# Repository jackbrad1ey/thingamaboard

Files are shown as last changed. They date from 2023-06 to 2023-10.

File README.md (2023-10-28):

# Thingamaboard

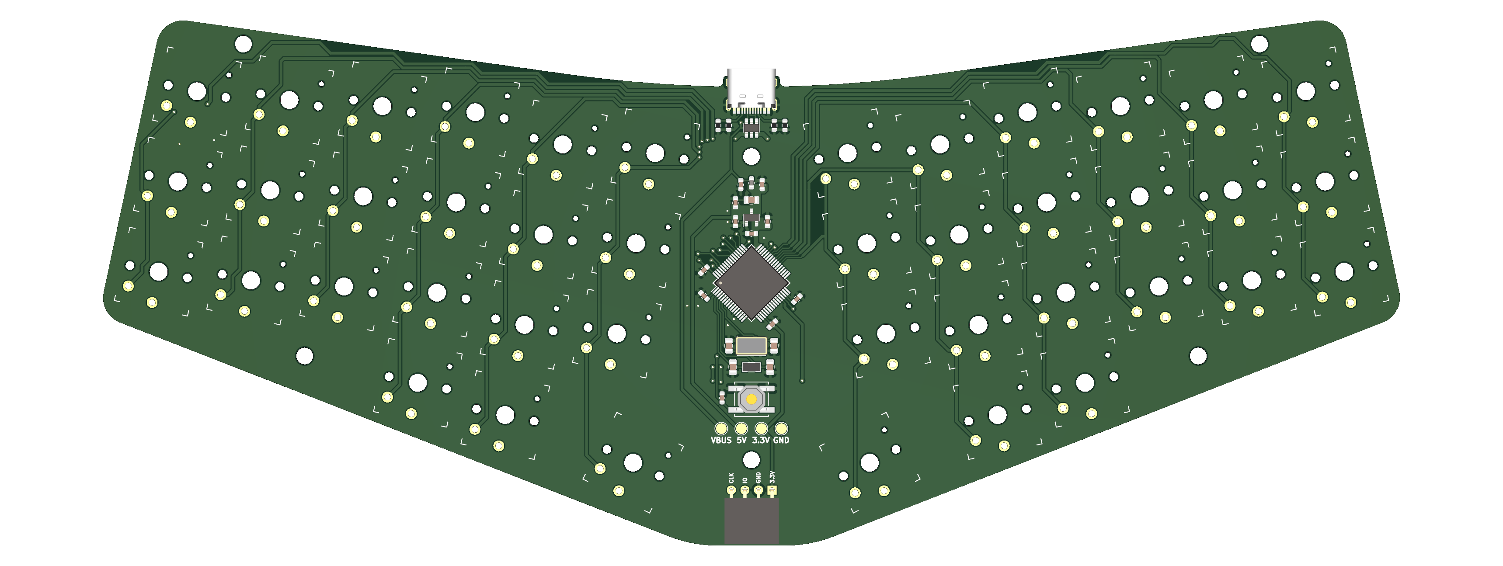
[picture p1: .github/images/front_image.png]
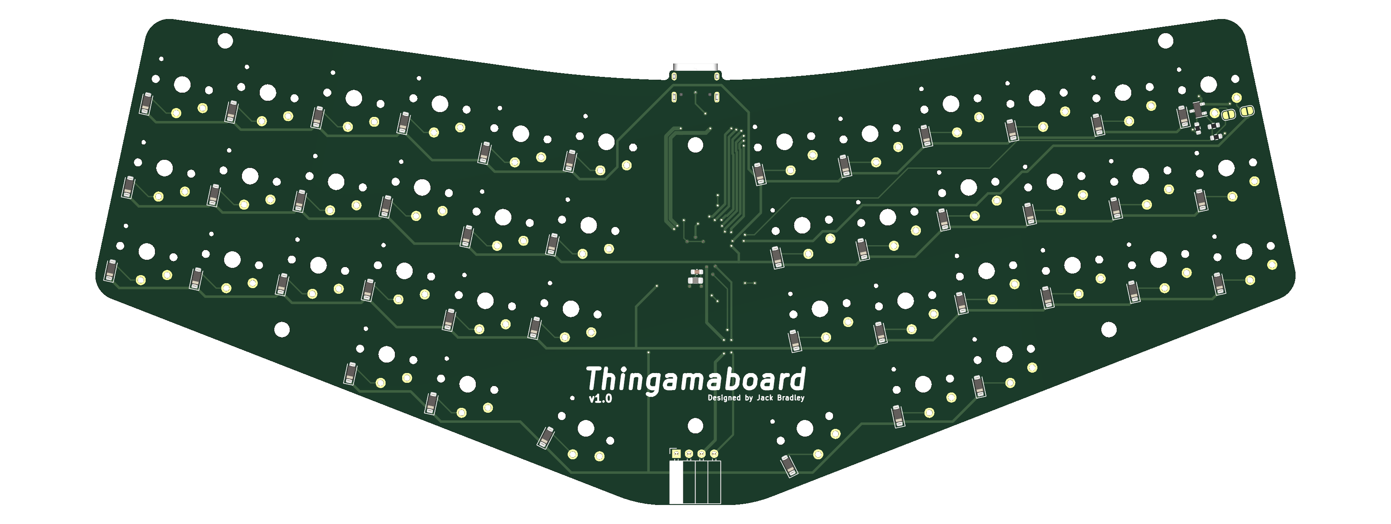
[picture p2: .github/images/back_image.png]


A custom keyboard designed and manufactured for myself. Programmed using STM32CubeIDE and Jetbrains Fleet, designed using [Ergogen](https://github.com/ergogen/ergogen), AutoCAD and Solidworks. This board was developed with portability and ergonomics in mind. It adopts a columnar, alice-like layout with three-key thumb clusters, allowing for ergonomic typing in a relatively small and portable form factor.

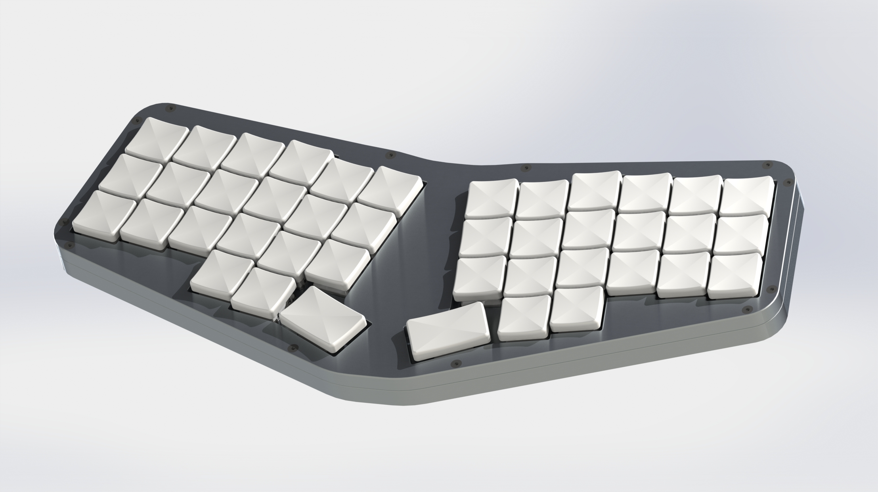
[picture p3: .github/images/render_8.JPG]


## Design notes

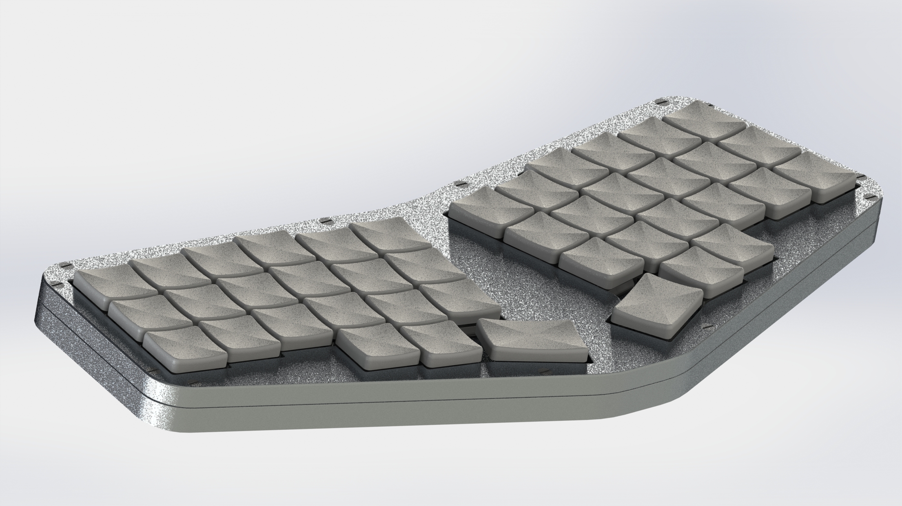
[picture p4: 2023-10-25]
.github/images/render_2.JPG

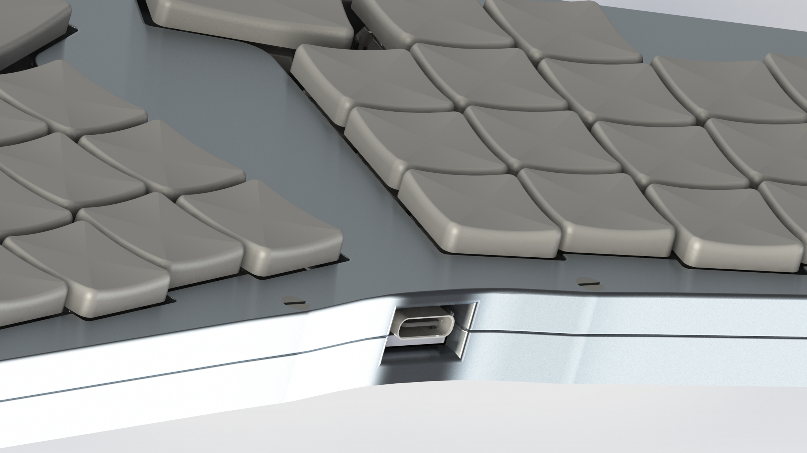
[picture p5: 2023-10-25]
.github/images/render_4.JPG

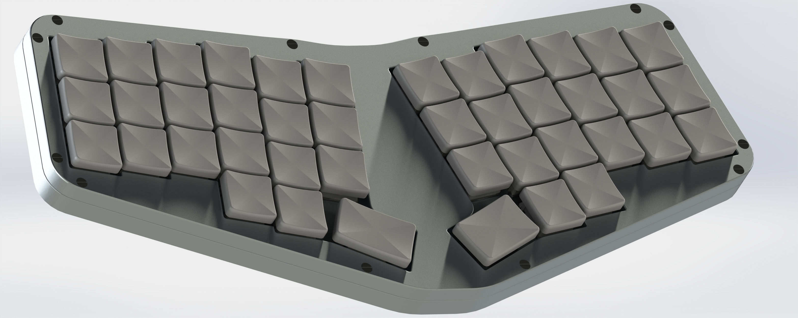
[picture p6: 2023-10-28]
.github/images/render_7.JPG

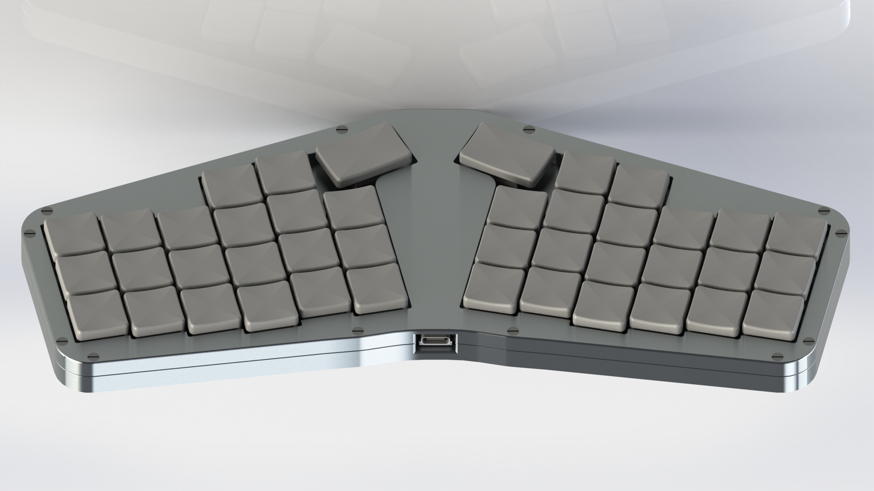
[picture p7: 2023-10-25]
.github/images/render_6.JPG

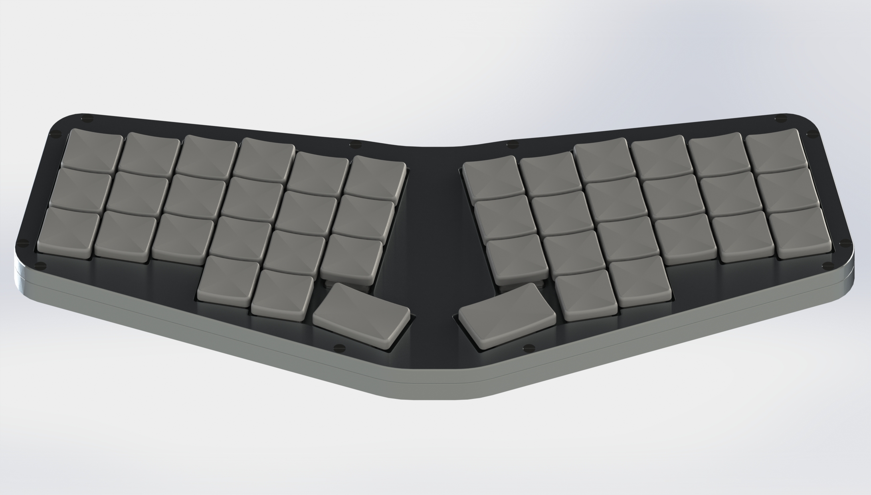
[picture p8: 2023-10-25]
.github/images/render_5.JPG

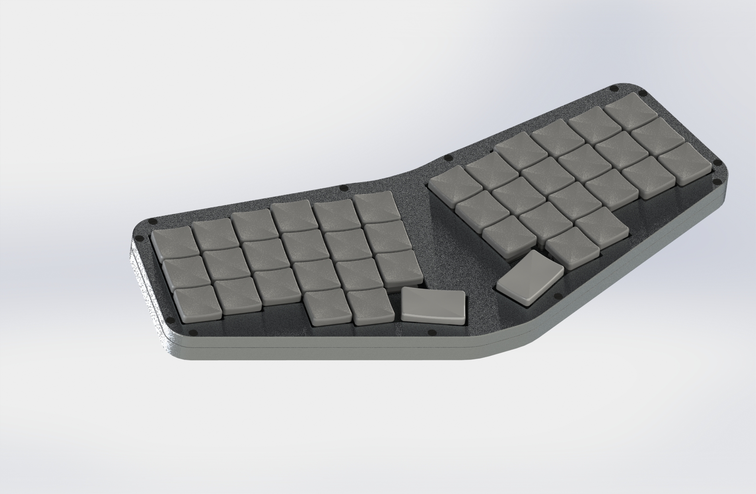
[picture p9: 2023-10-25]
.github/images/render_1.JPG

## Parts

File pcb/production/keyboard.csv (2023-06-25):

Comment | Designator | Footprint | LCSC
10n | C1,C10 | Capacitor_SMD:C_0603_1608Metric
4.7u | C14 | Capacitor_SMD:C_0603_1608Metric
0.1u | C17 | Capacitor_SMD:C_0603_1608Metric
100n | C2 | Capacitor_SMD:C_0603_1608Metric
10u | C3 | Capacitor_SMD:C_0805_2012Metric | C396720
1u | C4,C13,C16 | Capacitor_SMD:C_0603_1608Metric
100nF | C5,C11,C12,C15 | Capacitor_SMD:C_0603_1608Metric
33p | C6,C8 | Capacitor_SMD:C_0805_2012Metric | C157687
15p | C7,C9 | Capacitor_SMD:C_0805_2012Metric | C1562
D_Small | D1,D2,D3,D4,D5,D6,D7,D8,D9,D10,D11,D12,D13,D14,D15,D16,D17,D18,D19,D20,D21,D22,D23,D24,D25,D26,D27,D28,D29,D30,D31,D32,D33,D34,D35,D36,D37,D38,D39,D40,D41,D42 | Diode_SMD:D_SOD-123 | C2099
FerriteBead_Small | FB1 | Inductor_SMD:L_0603_1608Metric | C80165
MountingHole | H1,H2,H3,H4,H5,H6 | MountingHole:MountingHole_3.2mm_M3
USB_C_Receptacle_USB2.0 | J1 | local-library:TYPE-C-31-M-12 | C165948
Conn_01x04 | J2 | Connector_PinSocket_2.54mm:PinSocket_1x04_P2.54mm_Horizontal | C2897386
bridge | JP1,JP2 | Jumper:SolderJumper-2_P1.3mm_Open_RoundedPad1.0x1.5mm
10u | L1 | Inductor_SMD:L_0805_2012Metric
BC858 | Q2 | Package_TO_SOT_SMD:SOT-23 | C81569
10.2k | R1,R2,R3,R4,R5,R8 | Resistor_SMD:R_0603_1608Metric
1.91k | R7 | Resistor_SMD:R_0603_1608Metric
SW_Push | SW1,SW2,SW3,SW4,SW5,SW6,SW7,SW8,SW9,SW10,SW11,SW12,SW13,SW14,SW15,SW16,SW17,SW18,SW19,SW20,SW21,SW22,SW23,SW24,SW25,SW26,SW27,SW28,SW29,SW30,SW31,SW32,SW33,SW34,SW35,SW36,SW37,SW38,SW39,SW40,SW41,SW42 | local-library:SW_PG1350
TS-1187A-B-A-B | SW43 | Button_Switch_SMD:SW_Push_1P1T_NO_CK_KSC6xxJ | C318884
~ | TP1,TP2,TP3,TP4 | TestPoint:TestPoint_Pad_D2.0mm
LP3993-33B3F | U1 | Package_TO_SOT_SMD:SOT-23 | C387705
USBLC6-2SC6 | U2 | Package_TO_SOT_SMD:SOT-23-6 | C2827654
STM32F411RETx | U3 | Package_QFP:LQFP-64_10x10mm_P0.5mm
12MHz | Y1 | Crystal:Crystal_SMD_5032-4Pin_5.0x3.2mm
32.768k | Y2 | Crystal:Crystal_SMD_3215-2Pin_3.2x1.5mm | C620155

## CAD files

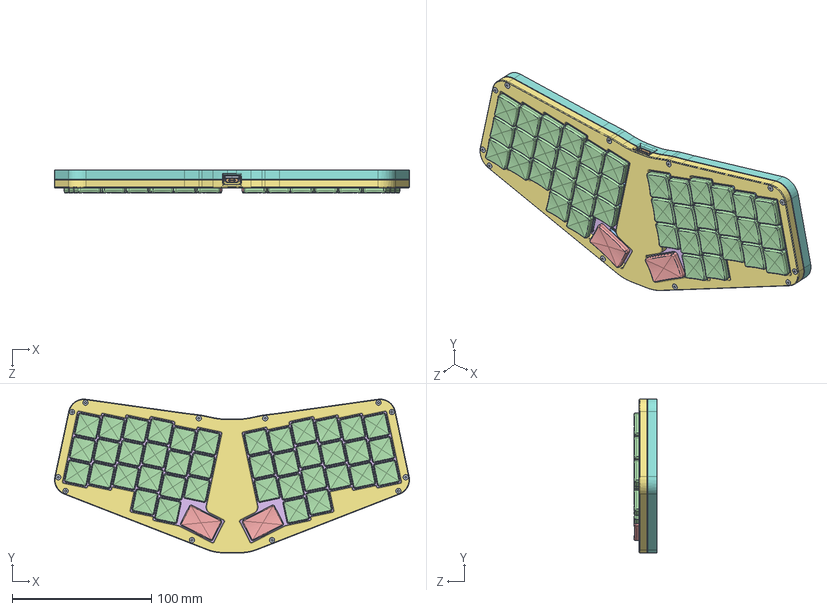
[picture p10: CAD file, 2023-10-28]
cad/thingamaboard.SLDASM
254.7 x 110.4 x 16.6 mm
pcb_base
usb_c_connector
kailh_choc_switch x 42
1U-keycap x 40
1.5U-keycap x 2
plate
new_top_piece
bottom_piece
M2_screws x 12

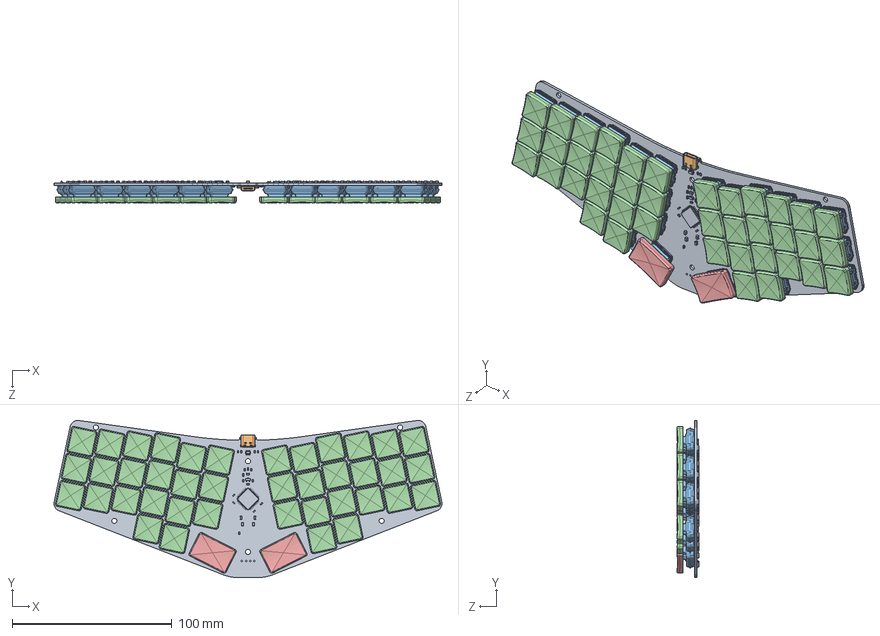
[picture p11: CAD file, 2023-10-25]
cad/pcb/pcb.SLDASM
242.5 x 98.2 x 13.8 mm
pcb_base
usb_c_connector
kailh_choc_switch x 42
1U-keycap x 40
1.5U-keycap x 2

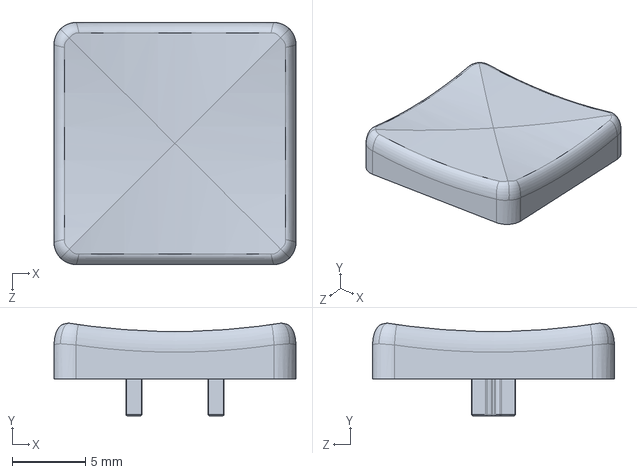
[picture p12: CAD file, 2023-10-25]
cad/pcb/1U-keycap.SLDPRT
16.5 x 6.32 x 16.5 mm

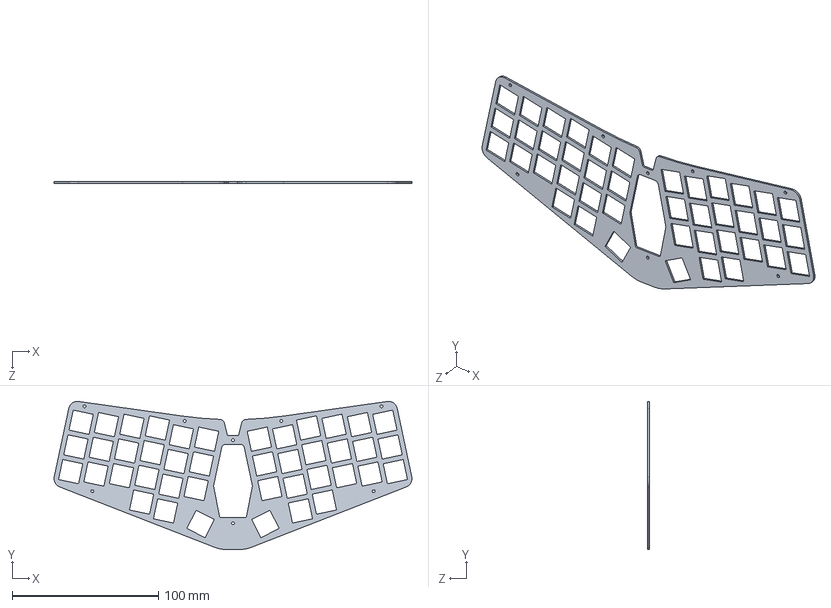
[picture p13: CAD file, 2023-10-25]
cad/plate/plate.SLDPRT
244.5 x 101.2 x 1.20 mm

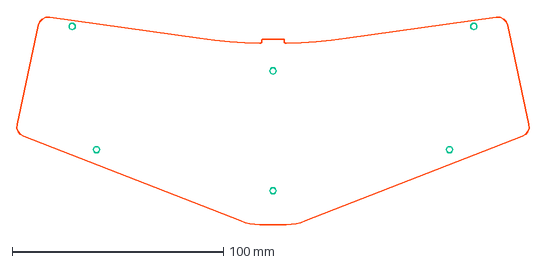
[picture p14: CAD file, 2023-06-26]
layout/pcb_shape.dxf
243.3 x 98.5 mm

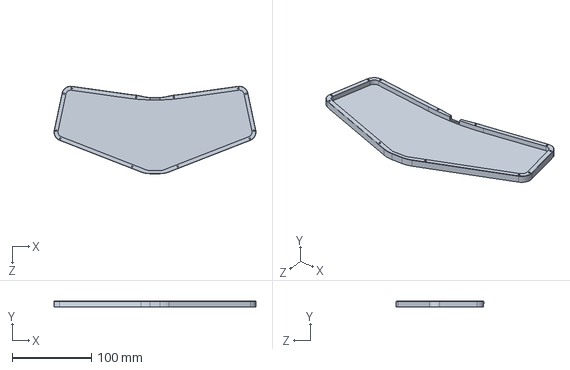
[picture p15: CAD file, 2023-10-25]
cad/case/bottom_piece.SLDPRT
254.7 x 7.00 x 110.4 mm

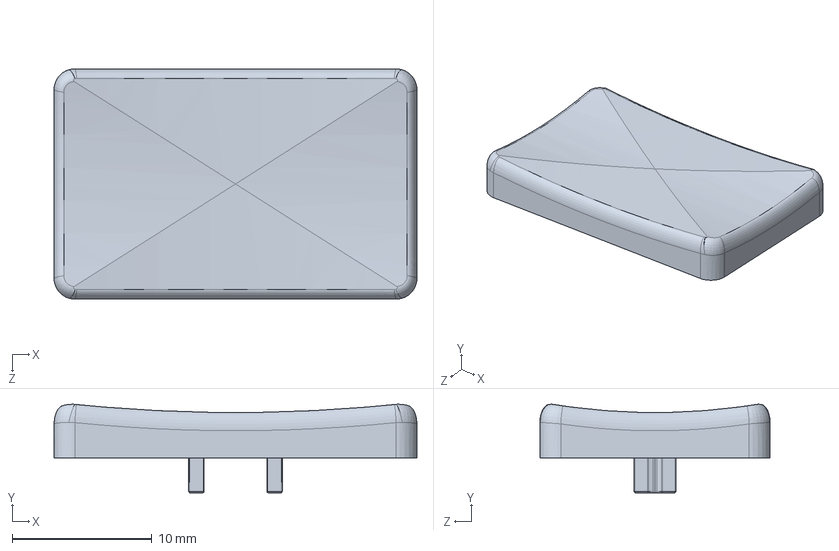
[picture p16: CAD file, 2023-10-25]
cad/pcb/1.5U-keycap.SLDPRT
26.0 x 6.35 x 16.5 mm

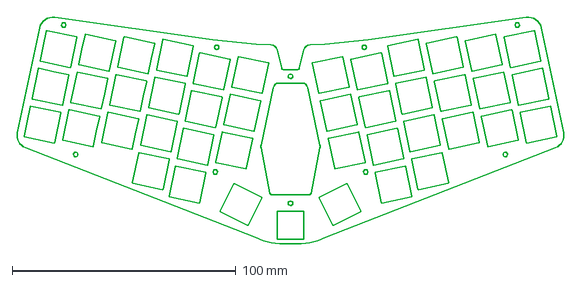
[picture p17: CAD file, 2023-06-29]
cad/plate/plate_outline.dxf
245.5 x 101.6 mm

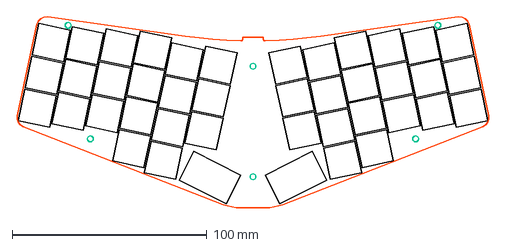
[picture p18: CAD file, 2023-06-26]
layout/pcb_layout.dxf
243.3 x 98.5 mm

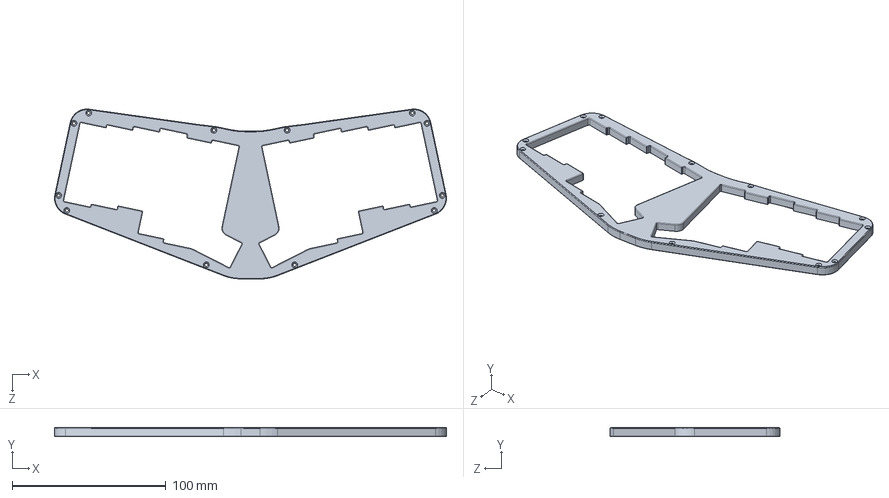
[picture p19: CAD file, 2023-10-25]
cad/case/new_top_piece.SLDPRT
254.7 x 6.00 x 110.4 mm

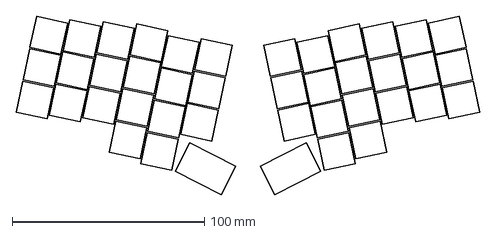
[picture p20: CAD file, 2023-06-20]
layout/key_layout.dxf
241.3 x 92.7 mm

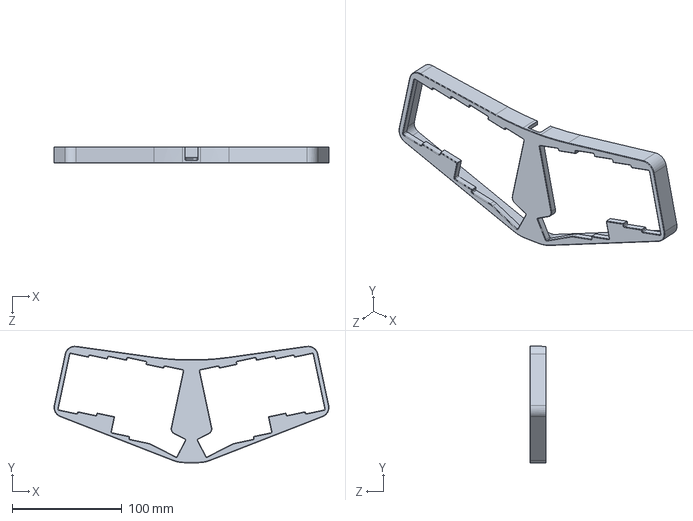
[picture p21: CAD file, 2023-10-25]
cad/case/top_piece.SLDPRT
250.5 x 106.2 x 15.0 mm

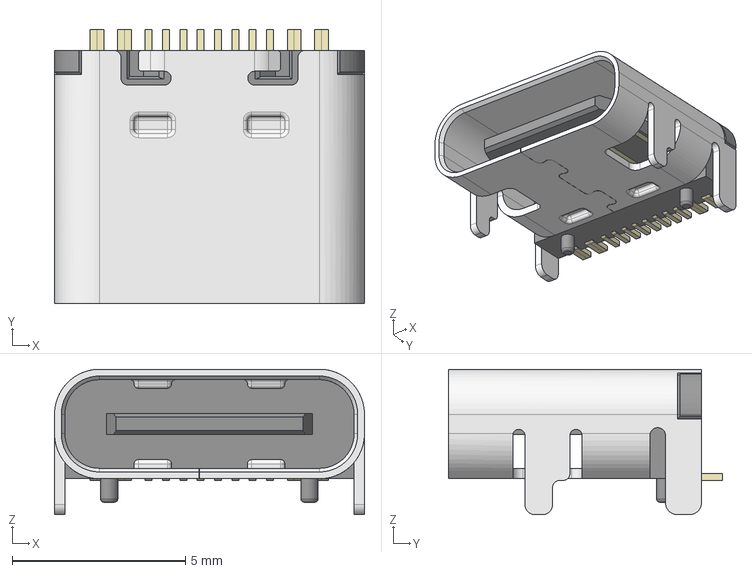
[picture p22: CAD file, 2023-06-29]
cad/pcb/usb_c_connector.step
8.95 x 7.90 x 4.20 mm

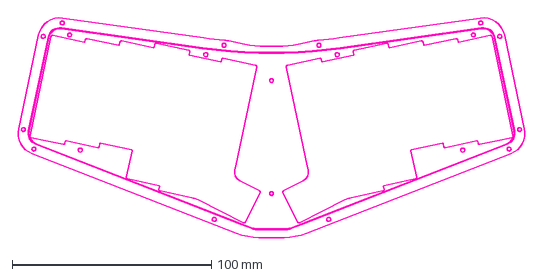
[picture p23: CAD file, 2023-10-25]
cad/case/case_mount_outline.dxf
256.5 x 111.1 mm

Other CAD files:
cad/outlines.dwg
cad/pcb/kailh_choc_switch.SLDPRT
cad/pcb/female_1x4_2.54mm_header.SLDPRT
cad/case/M2_screws.SLDPRT
cad/case/case_mount_outline.dwg
cad/pcb/usb_c_connector.SLDPRT
layout/pcb_layout.dwg

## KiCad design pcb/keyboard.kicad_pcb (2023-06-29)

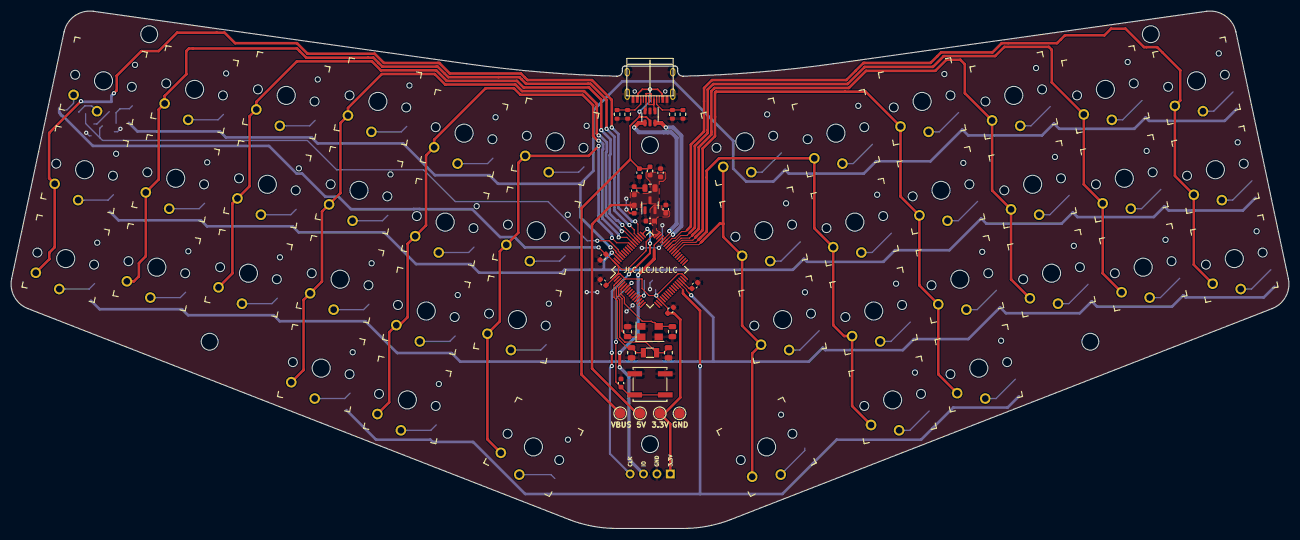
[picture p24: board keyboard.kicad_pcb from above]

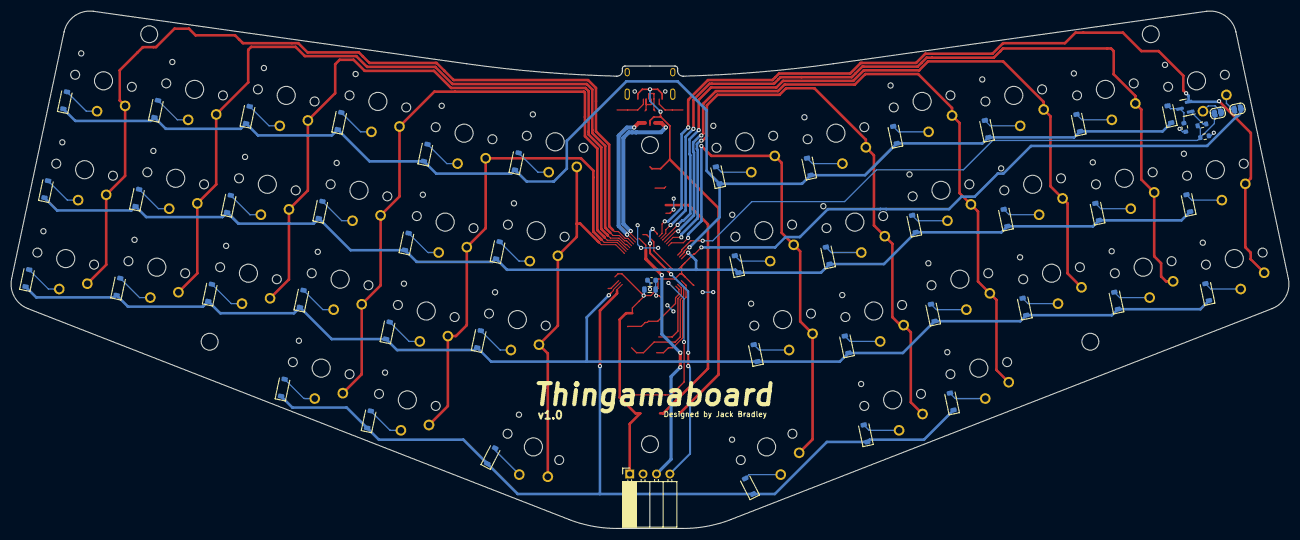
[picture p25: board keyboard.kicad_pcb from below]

Board: 2 copper layers, 242.5 x 98.2 mm, 131 parts (51 on the bottom side), 81 nets.

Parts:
C1, C10: 10n; C_0603_1608Metric
C2: 100n; C_0603_1608Metric
C3: 10u; C_0805_2012Metric
C4, C13, C16: 1u; C_0603_1608Metric
C5, C11, C12, C15: 100nF; C_0603_1608Metric
C6, C8: 33p; C_0805_2012Metric
C7, C9: 15p; C_0805_2012Metric
C14: 4.7u; C_0603_1608Metric
C17: 0.1u; C_0603_1608Metric
D1, D2, D3, D4, D5, D6, D7, D8, D9, D10, D11, D12, D13, D14, D15, D16, D17, D18, D19, D20, D21, D22, D23, D24, D25, D26, D27, D28, D29, D30, D31, D32, D33, D34, D35, D36, D37, D38, D39, D40, D41, D42: D_Small; D_SOD-123
FB1: FerriteBead_Small; L_0603_1608Metric
H1, H2, H3, H4, H5, H6: MountingHole; MountingHole_3.2mm_M3
J1: USB_C_Receptacle_USB2.0; TYPE-C-31-M-12
J2: Conn_01x04; PinSocket_1x04_P2.54mm_Horizontal
JP1, JP2: bridge; SolderJumper-2_P1.3mm_Open_RoundedPad1.0x1.5mm
L1: 10u; L_0805_2012Metric
Q2: BC858; SOT-23
R1, R2, R3, R4, R5, R8: 10.2k; R_0603_1608Metric
R7: 1.91k; R_0603_1608Metric
SW1, SW2, SW3, SW4, SW5, SW6, SW7, SW8, SW9, SW10, SW11, SW12, SW13, SW14, SW15, SW16, SW17, SW18, SW19, SW20, SW21, SW22, SW23, SW24, SW25, SW26, SW27, SW28, SW29, SW30, SW31, SW32, SW33, SW34, SW35, SW36, SW37, SW38, SW39, SW40, SW41, SW42: SW_Push; SW_PG1350
SW43: TS-1187A-B-A-B; SW_Push_1P1T_NO_CK_KSC6xxJ
TP1, TP2, TP3, TP4: TestPoint_Pad_D2.0mm
U1: LP3993-33B3F; SOT-23
U2: USBLC6-2SC6; SOT-23-6
U3: STM32F411RETx; LQFP-64_10x10mm_P0.5mm
Y1: 12MHz; Crystal_SMD_5032-4Pin_5.0x3.2mm
Y2: 32.768k; Crystal_SMD_3215-2Pin_3.2x1.5mm

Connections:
+3V3: C10.1, C11.1, C12.1, C13.1, C16.1, J2.1, JP1.2 (B), L1.1, TP4.1, U1.2 (VOUT), U3.1 (VBAT), U3.19 (VDD), U3.32 (VDD), U3.48 (VDD), U3.64 (VDD)
+5V: C2.1, C3.1, C4.1, C5.1, FB1.2, TP2.1, U1.3 (VIN)
/connectors/CC1: J1.A5 (CC1), R1.1, R2.1
/connectors/CC2: J1.B5 (CC2), R3.1, R4.1
/connectors/SWCLK: J2.4, U3.49 (PA14)
/connectors/SWDIO: J2.3, U3.46 (PA13)
/connectors/USB_D+: U2.4 (I/O2), U3.45 (PA12)
/connectors/USB_D-: U2.6 (I/O1), U3.44 (PA11)
/inputs/BOOT0: JP2.1 (A), R5.1, R7.1, U3.60 (BOOT0)
/inputs/NRST: C17.1, SW43.2, U3.7 (NRST)
/inputs/S1_OUT: D1.2 (A), Q2.3 (C), R8.1
/inputs/col0: Q2.2 (E), SW2.2, SW3.2, U3.50 (PA15)
/inputs/col1: SW4.2, SW5.2, SW6.2, U3.51 (PC10)
/inputs/col2: SW7.2, SW8.2, SW9.2, U3.52 (PC11)
/inputs/col3: SW10.2, SW11.2, SW12.2, SW13.2, U3.53 (PC12)
/inputs/col4: SW14.2, SW15.2, SW16.2, SW17.2, U3.54 (PD2)
/inputs/col5: SW18.2, SW19.2, SW20.2, SW21.2, U3.55 (PB3)
/inputs/col6: SW22.2, SW23.2, SW24.2, SW25.2, U3.38 (PC7)
/inputs/col7: SW26.2, SW27.2, SW28.2, SW29.2, U3.39 (PC8)
/inputs/col8: SW30.2, SW31.2, SW32.2, SW33.2, U3.40 (PC9)
/inputs/col9: SW34.2, SW35.2, SW36.2, U3.41 (PA8)
/inputs/col10: SW37.2, SW38.2, SW39.2, U3.42 (PA9)
/inputs/col11: SW40.2, SW41.2, SW42.2, U3.43 (PA10)
/inputs/row0: D1.1 (K), D4.1 (K), D7.1 (K), D10.1 (K), D14.1 (K), D18.1 (K), D22.1 (K), D26.1 (K), D30.1 (K), D34.1 (K), D37.1 (K), D40.1 (K), U3.61 (PB8)
/inputs/row1: D2.1 (K), D5.1 (K), D8.1 (K), D11.1 (K), D15.1 (K), D19.1 (K), D23.1 (K), D27.1 (K), D31.1 (K), D35.1 (K), D38.1 (K), D41.1 (K), U3.62 (PB9)
/inputs/row2: D3.1 (K), D6.1 (K), D9.1 (K), D12.1 (K), D16.1 (K), D20.1 (K), D24.1 (K), D28.1 (K), D32.1 (K), D36.1 (K), D39.1 (K), D42.1 (K), U3.29 (PB10)
/inputs/row3: D13.1 (K), D17.1 (K), D21.1 (K), D25.1 (K), D29.1 (K), D33.1 (K), U3.28 (PB2)
/stm32/HSEO_IN: C6.1, U3.5 (PH0), Y1.1
/stm32/HSEO_OUT: C8.1, U3.6 (PH1), Y1.3
/stm32/LSEO_IN: C7.1, U3.3 (PC14), Y2.1
/stm32/LSEO_OUT: C9.1, U3.4 (PC15), Y2.2
GND: C1.2, C2.2, C3.2, C4.2, C5.2, C6.2, C7.2, C8.2, C9.2, C10.2, C11.2, C12.2, C13.2, C14.2, C15.2, C16.2, C17.2, J1.A1 (GND), J1.A12 (GND), J1.B1 (GND), J1.B12 (GND), J1.S1 (SHIELD), J2.2, R1.2, R2.2, R3.2, R4.2, R5.2, R8.2, SW43.1, TP3.1, U1.1 (GND), U2.2 (GND), U3.12 (VSSA), U3.18 (VSS), U3.31 (VSS), U3.47 (VSS), U3.63 (VSS), Y1.2, Y1.4
unnamed: D2.2 (A), SW2.1
unnamed: D3.2 (A), SW3.1
unnamed: D4.2 (A), SW4.1
unnamed: D5.2 (A), SW5.1
unnamed: D6.2 (A), SW6.1
unnamed: D7.2 (A), SW7.1
unnamed: D8.2 (A), SW8.1
unnamed: D9.2 (A), SW9.1
unnamed: D10.2 (A), SW10.1
unnamed: D11.2 (A), SW11.1
unnamed: D12.2 (A), SW12.1
unnamed: D13.2 (A), SW13.1
unnamed: D14.2 (A), SW14.1
unnamed: D15.2 (A), SW15.1
unnamed: D16.2 (A), SW16.1
unnamed: D17.2 (A), SW17.1
unnamed: D18.2 (A), SW18.1
unnamed: D19.2 (A), SW19.1
unnamed: D20.2 (A), SW20.1
unnamed: D21.2 (A), SW21.1
unnamed: D22.2 (A), SW22.1
unnamed: D23.2 (A), SW23.1
unnamed: D24.2 (A), SW24.1
unnamed: D25.2 (A), SW25.1
unnamed: D26.2 (A), SW26.1
unnamed: D27.2 (A), SW27.1
unnamed: D28.2 (A), SW28.1
unnamed: D29.2 (A), SW29.1
unnamed: D30.2 (A), SW30.1
unnamed: D31.2 (A), SW31.1
unnamed: D32.2 (A), SW32.1
unnamed: D33.2 (A), SW33.1
unnamed: D34.2 (A), SW34.1
unnamed: D35.2 (A), SW35.1
unnamed: D36.2 (A), SW36.1
unnamed: D37.2 (A), SW37.1
unnamed: D38.2 (A), SW38.1
unnamed: D39.2 (A), SW39.1
unnamed: D40.2 (A), SW40.1
unnamed: D41.2 (A), SW41.1
unnamed: D42.2 (A), SW42.1
unnamed: J1.A6 (D+), J1.B6 (D+), U2.3 (I/O2)
unnamed: J1.A7 (D-), J1.B7 (D-), U2.1 (I/O1)
unnamed: JP1.1 (A), SW1.2
unnamed: JP2.2 (B), SW1.1
unnamed: Q2.1 (B), R7.2
unnamed: C14.1, U3.30 (VCAP1)
unnamed: C15.1, L1.2, U3.13 (VDDA)
VBUS: C1.1, FB1.1, J1.A4 (VBUS), J1.A9 (VBUS), J1.B4 (VBUS), J1.B9 (VBUS), TP1.1, U2.5 (VBUS)

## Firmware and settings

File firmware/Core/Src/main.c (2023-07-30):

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
/* Includes ------------------------------------------------------------------*/
#include "main.h"
#include "usb_device.h"

/* USER CODE BEGIN Includes */
#include "key_scan.h"
#include "keycodes.h"
#include "usbd_hid.h"
/* USER CODE END Includes */

TIM_HandleTypeDef htim2;

/* USER CODE BEGIN PV */
extern USBD_HandleTypeDef hUsbDeviceFS;

int keys[KEYS_PER_REPORT] = {KEY_NONE};
int modifier_byte = 0;

void delay_us(uint16_t us) {
	__HAL_TIM_SET_COUNTER(&htim2, 0);  // reset counter back to 0
	while (__HAL_TIM_GET_COUNTER(&htim2) < us);  // wait for the counter to reach desired time
}

uint8_t HID_IsIdle(USBD_HandleTypeDef *pdev) {
	return ((USBD_HID_HandleTypeDef *)pdev->pClassData)->state == HID_IDLE;
}

/* USER CODE END PV */

void SystemClock_Config(void);
static void MX_GPIO_Init(void);
static void MX_TIM2_Init(void);
/**
  * @brief  The application entry point.
  * @retval int
  */
int main(void)
{
  /* MCU Configuration--------------------------------------------------------*/

  /* Reset of all peripherals, Initializes the Flash interface and the Systick. */
  HAL_Init();

  /* Configure the system clock */
  SystemClock_Config();

  /* Initialize all configured peripherals */
  MX_GPIO_Init();
  MX_USB_DEVICE_Init();
  MX_TIM2_Init();
  /* USER CODE BEGIN 2 */
  HAL_TIM_Base_Start(&htim2);
  Keyboard report = (Keyboard) {0, 0, KEY_NONE, KEY_NONE, KEY_NONE, KEY_NONE, KEY_NONE, KEY_NONE};
  /* USER CODE END 2 */

  /* Infinite loop */
  /* USER CODE BEGIN WHILE */
  while (1)
  {
    /* USER CODE END WHILE */

    /* USER CODE BEGIN 3 */
//	HAL_Delay(7);
	// wait until our last report has been read
	if (!HID_IsIdle(&hUsbDeviceFS)) {
		continue;
	}

	scan_keys(keys, &modifier_byte);
	report = (Keyboard) {modifier_byte, 0, keys[0], keys[1], keys[2], keys[3], keys[4], keys[5]};

	USBD_HID_SendReport(&hUsbDeviceFS, &report, sizeof(report));

	for (int i=0; i < KEYS_PER_REPORT; i++) {
		keys[i] = KEY_NONE;
	}
	modifier_byte = 0;

//	report = (Keyboard) {0, 0, KEY_H, KEY_I, 0, 0, 0, 0};
//	USBD_HID_SendReport(&hUsbDeviceFS, &report, sizeof(report));
//	HAL_Delay(50);
//	report = (Keyboard) {0, 0, 0, 0, 0, 0, 0, 0};
//	USBD_HID_SendReport(&hUsbDeviceFS, &report, sizeof(report));
//	HAL_Delay(2000);
  }
  /* USER CODE END 3 */
}

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


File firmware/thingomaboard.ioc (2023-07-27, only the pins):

Mcu.UserName=STM32F411RETx
PA10.Signal=GPIO_Output
PA11.Signal=USB_OTG_FS_DM
PA12.Signal=USB_OTG_FS_DP
PA13.Signal=SYS_JTMS-SWDIO
PA14.Signal=SYS_JTCK-SWCLK
PA15.Signal=GPIO_Output
PA8.Signal=GPIO_Output
PA9.Signal=GPIO_Output
PB10.Signal=GPIO_Input
PB2.Signal=GPIO_Input
PB3.Signal=GPIO_Output
PB8.Signal=GPIO_Input
PB9.Signal=GPIO_Input
PC10.Signal=GPIO_Output
PC11.Signal=GPIO_Output
PC12.Signal=GPIO_Output
PC14-OSC32_IN.Signal=RCC_OSC32_IN
PC15-OSC32_OUT.Signal=RCC_OSC32_OUT
PC7.Signal=GPIO_Output
PC8.Signal=GPIO_Output
PC9.Signal=GPIO_Output
PD2.Signal=GPIO_Output

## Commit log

2023-06-19 initial work on layout
    [key_layout.dxf, pcb_outline.dwg]
2023-06-19 Started initial work on PCB, added mounting holes to layout
    [keyboard.kicad_pcb, keyboard.kicad_sch, pcb_outline.dwg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]
2023-06-20 Modified layout further
    [key_layout.dxf, keyboard.kicad_pcb, keyboard.kicad_sch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]
2023-06-21 Working on schematic and PCB
    [connectors.kicad_sch, inputs.kicad_sch, keyboard.kicad_pcb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]
2023-06-22 Finished off schematic
    [connectors.kicad_sch, inputs.kicad_sch, keyboard.kicad_pcb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]
2023-06-22 Fixed up footprints, added readme
    [power.kicad_sch]
2023-06-23 Started routing
    [connectors.kicad_sch, keyboard.kicad_pcb, pcb_layout.dwg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]
2023-06-23 Continued routing
    [keyboard.kicad_pcb]
2023-06-24 Finished routing, ready for checks
    [connectors.kicad_sch, inputs.kicad_sch, keyboard.kicad_pcb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]
2023-06-24 Creating production files
    [connectors.kicad_sch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]
2023-06-24 Added name to silkscreen, updated prod files
    [keyboard-B_Cu.gbr, keyboard-B_Mask.gbr, keyboard-B_Paste.gbr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]
2023-06-24 Generated BOM
    [keyboard.csv]
2023-06-25 Done, sent off for manufacturing
    [keyboard.csv]
2023-06-26 Started working on the cad
    [$tempfile$.step, Kailh Choc Low Profile Switch.step, female_1x4_2.54mm_header.SLDPRT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]
2023-06-27 Started work on plate
    [$tempfile$.step, keyboard.kicad_pcb, plate_layout.dwg]
2023-06-27 Continued work on plate
    [plate_layout.dwg]
2023-06-28 Working on plate
    [plate_layout.dwg]
2023-06-28 Continued plate design
    [plate_layout.dwg]
2023-06-29 Designed basic top plate outline
    [case_mount_outline.dxf, outlines.dwg, plate.SLDPRT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]
2023-06-29 Did a basic test fit in cad with the top case piece
    [thingamaboard.SLDASM, top_piece.SLDPRT]
2023-07-01 Updated outline a lil
    [case_mount_outline.dxf, outlines.dwg, thingamaboard.SLDASM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]
2023-07-02 Worked on top plate
    [plate.SLDPRT, thingamaboard.SLDASM, top_piece.SLDPRT]
2023-07-04 Setup accurate us timer
2023-07-04 cadded 1U keycaps
    [1U-keycaps.SLDPRT, pcb.SLDASM]
2023-07-04 Extended top case width
    [1.5U-keycap.SLDPRT, 1U-keycap.SLDPRT, 1U-keycaps.SLDPRT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]
2023-07-05 Slight change
    [thingamaboard.SLDASM, top_piece.SLDPRT]
2023-07-06 Worked on top case
    [thingamaboard.SLDASM, top_piece.SLDPRT]
2023-07-07 Continued work on case
    [thingamaboard.SLDASM, top_piece.SLDPRT]
2023-07-09 Modified HID middleware to keyboard HID device
2023-07-10 Fixed some small bugs
    [key_scan.c, main.c]
2023-07-17 Added interactive BOM for assembly
2023-07-30 Working on CAD
    [pcb.SLDASM, plate.SLDPRT, thingamaboard.SLDASM]
2023-07-30 Fixed up firmware keypresses
    [main.c]
2023-10-25 Case design done
    [1.5U-keycap.SLDPRT, 1U-keycap.SLDPRT, M2_screws.SLDPRT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]
2023-10-28 Continued case CAD, made renders
    [M2_screws.SLDPRT, thingamaboard.SLDASM]
2023-10-28 Added case render

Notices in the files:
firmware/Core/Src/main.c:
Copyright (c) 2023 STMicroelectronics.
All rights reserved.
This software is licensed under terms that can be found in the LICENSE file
